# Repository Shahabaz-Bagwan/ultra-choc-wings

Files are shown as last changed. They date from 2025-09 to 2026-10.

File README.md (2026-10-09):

# Ultra Choc Wings

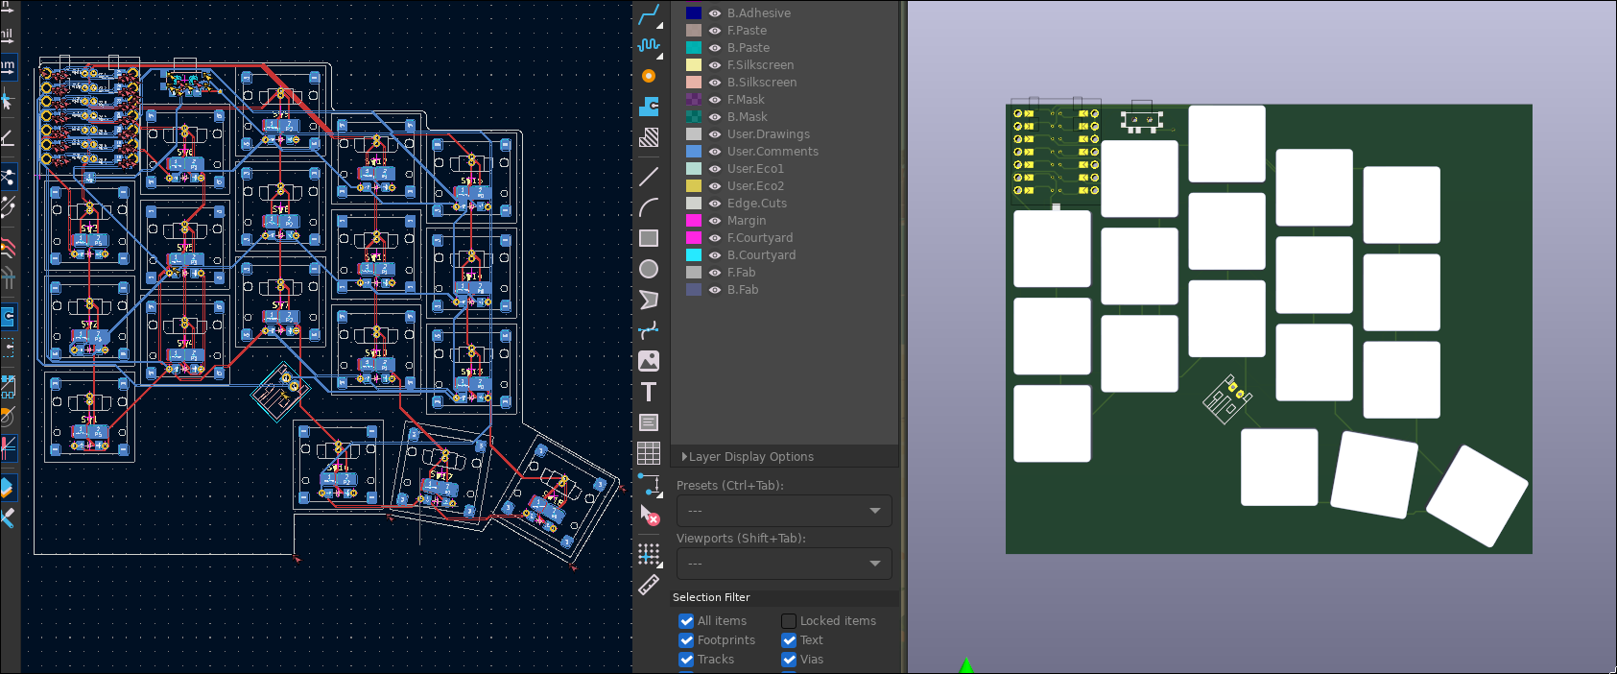
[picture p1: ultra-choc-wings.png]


A 36-key split keyboard for Kailh PG1316S switches, based on the
[Triboard](https://github.com/tarneaux/triboard).

* **36 keys**: 3×5 plus 3 thumb keys per half.
* **Chocofi layout**: 18 × 17 mm key spacing, the same column stagger and the
  same thumb cluster (0°, 15°, 30° fan) as the
  [chocofi](https://github.com/pashutk/chocofi), so keymaps, keycaps and muscle
  memory carry over. The stagger is Fifi's, which Chocofi kept in mm.
* **One reversible PCB** for both halves. The right half is the same board
  flipped over.
* **Per-key LEDs** (single colour, PWM dimmed, off by default).
* **CR2032 coin cell** per half, with a power switch.
* **ZMK with a dongle**: a third XIAO nRF52840 on USB is the central, both
  halves are low-power peripherals.
* **Seeed XIAO nRF52840** on each half.
* **JLCPCB ready**: gerbers, BOM and placement files for both halves; all SMD
  parts are assembled by JLCPCB on one side per half.
* **Two cases**: a thin folding case after Aronia's (opens flat as a uniboard,
  folds shut), and split trays that a tool-free slide-on clip joins into a rigid uniboard,
  or that work apart.

| Folder | What's in it |
| --- | --- |
| `config.yaml`, `footprints/` | Ergogen source of the PCB |
| `pcb/` | Routed KiCad board and DRC report |
| `jlcpcb/` | Gerbers, BOM and CPL files, [ordering guide](jlcpcb/README.md) |
| `firmware/` | ZMK config: dongle, left, right, keymap |
| `case/` | Folding and split cases, [notes](case/README.md) |
| `docs/power.md` | [Coin cell vs. LEDs](docs/power.md), the power budget |
| `archive/v1-lipo/` | The earlier hand-routed LiPo version |

## Coin cell and LEDs

A CR2032 cannot run 18 LEDs for long. The LEDs share one MOSFET, so when they
are off they draw nothing; the firmware keeps them off at boot, starts them at
10 % when you toggle them on (LOWER + RAISE, then `BL_TOG`), and turns them off
whenever the half goes idle. See [docs/power.md](docs/power.md) for the numbers
and the option of running from a LiPo instead.

## Firmware

`firmware/` is a ZMK user config (ZMK v0.3). GitHub Actions builds it on every
push (`.github/workflows/zmk.yml`); download the `firmware` artifact and flash:

* `ultra_choc_wings_dongle` onto the XIAO that stays plugged into the computer,
* `ultra_choc_wings_left` and `ultra_choc_wings_right` onto the halves,
* `settings_reset` first if the boards were paired to something before.

The keymap is `firmware/ultra_choc_wings.keymap` (QWERTY with LOWER, RAISE and
ADJUST layers).

## Building the PCB

```sh
npm install
KICAD_PYTHON=python3 FREEROUTING_JAR=path/to/freerouting.jar scripts/build_pcb.sh
```

This runs Ergogen, autoroutes with [Freerouting](https://github.com/freerouting/freerouting),
joins the few connections Freerouting misreads around the flippable XIAO
pads (`scripts/finish_routes.py`), adds ground pours on both layers, writes a DRC report, exports gerbers, the
JLCPCB BOM/CPL files, the schematic and the cases. It needs KiCad 7 or newer (with its Python
module), Java, and `xvfb-run` on a headless machine. The committed board was
autorouted; review it in KiCad before ordering and hand-tidy any routes you
don't like.

`pcb/drc.rpt` has no unconnected items. The remaining entries are known: the
flippable XIAO footprint's solder jumpers sit closer than the default clearance
and hole clearance by design, solder mask bridges between those jumpers,
library-footprint notes (KiCad compares the generated footprints with the
`ucw` library), and silkscreen overlaps.

## Schematic and libraries

The board comes from Ergogen, so `scripts/make_schematic.py` writes the
KiCad side from the routed board (it runs as part of `build_pcb.sh`):

* `pcb/ultra-choc-wings.kicad_sch`: every part of one half with its nets,
  as net labels, grouped into the key matrix, MCU, power and LED driver.
* `pcb/ucw.kicad_sym`: one symbol per part type.
* `pcb/ucw.pretty/`: one footprint per part type, taken from the board.
* `pcb/fp-lib-table`, `pcb/sym-lib-table`: point the project at both.

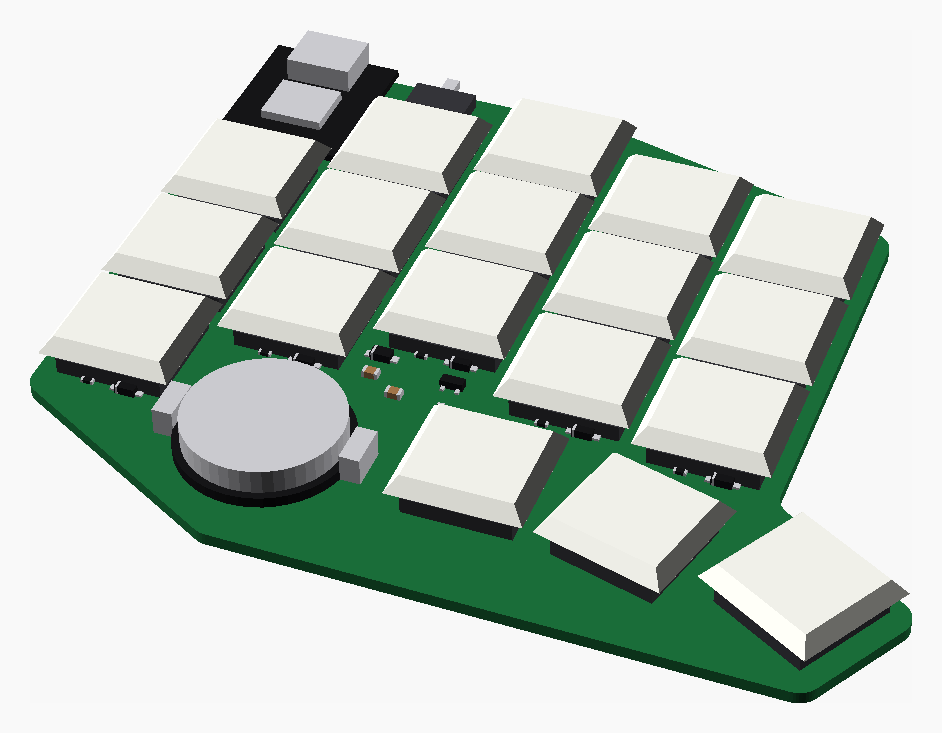
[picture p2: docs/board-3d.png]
The board with parts and keycaps


Every part also has a simple 3D model (`pcb/ucw.3dshapes/`, boxes and
cylinders from the datasheet outlines, not exact CAD), so KiCad's 3D viewer
shows the populated board; `docs/board-3d-parts.png` is the same without
keycaps. `scripts/make_3d_models.py` writes them and links them into the board
and the `ucw` footprints. The models sit on the switch side, the front (F)
for the left half.

Every footprint on the board is linked to its `ucw` footprint and to its
schematic symbol, so cross-probing and "Update PCB from Schematic" match part
for part. Change the design in `config.yaml` and rerun the build rather than
editing the schematic; the build overwrites it.

## Assembly notes

* All SMD parts, the switches and the XIAO go on the **same side** of each
  PCB: the front for the left half, the back for the right half.
* Bridge the `[> ]` jumper pads under the XIAO on the side the XIAO sits on.
* Wire the **RAW** pad (next to the XIAO) to the BAT+ pad under the XIAO.

## Credits

- Inspiration: keyboards by [GEIGEIGEIST](https://github.com/GEIGEIGEIST), the [chocofi](https://github.com/pashutk/chocofi) and the [samoklava](https://github.com/wxsh/samoklava).
- Videos by Ben Vallack on YouTube.
- Kind people on the [ErgoMechKeyboards](https://lemmy.ml/c/ergomechkeyboards@lemmy.world) Lemmy community.
- FlatFootFox - [Let's Design A Keyboard With Ergogen v4](https://flatfootfox.com/ergogen-introduction/)

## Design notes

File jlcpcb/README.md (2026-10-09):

# Ordering from JLCPCB

One PCB design is used for both halves. Order it twice: once assembled on the
top side (left half), once assembled on the bottom side (right half). The
gerbers are identical.

| File | Use |
| --- | --- |
| `gerbers.zip` | PCB, 2 layers, 1.6 mm. Same file for both orders. |
| `bom.csv` | Bill of materials (LCSC part numbers). Same file for both orders. |
| `cpl-left-top.csv` | Placement for the **left** half: assemble **Top side**. |
| `cpl-right-bottom.csv` | Placement for the **right** half: assemble **Bottom side**. |

Every SMD part is on the switch side, so each half only needs single-side
assembly. The reversible footprints mirror their copper on the back, which is
why the right half can use the exact same board flipped over;
`scripts/jlcpcb.py` checks that no copper moves when the parts are flipped.

## What JLCPCB assembles

| Ref | Part | LCSC |
| --- | --- | --- |
| D1–D18 | 1N4148WS matrix diodes (SOD-323) | C2128 |
| D19 | B5819W Schottky, reverse protection for the coin cell | C8598 |
| L1–L18 | Red LED 0603 (per key) | C2286 |
| R1–R18 | 1 kΩ 0603 (LED current) | C21190 |
| R19 | 100 kΩ 0603 (MOSFET gate pull-down) | C25803 |
| C1, C2 | 22 µF 0805 (buffer for the coin cell) | C45783 |
| Q1 | AO3400A N-MOSFET (LED switch) | C20917 |
| T1 | SPDT slide switch, power | C128955 |

Check stock and the rotation preview on JLCPCB's site before paying; the
rotations come straight from KiCad and polarised parts (diodes, LEDs, Q1) are
the ones to look at.

## What you solder yourself

* 18 Kailh PG1316S switches per half (SW1–SW18), on the same side as the parts.
* Seeed XIAO nRF52840 per half, plus one more for the dongle (no PCB needed).
  Mount it on the switch side and bridge the `[> ]` jumper pads under it on
  that side.
* CR2032 holder (BT1), MPD BC-2003 or Q&J CR2032-BS-6-1 land pattern. It is
  left out of the BOM because stock of these varies; add it to the order if
  JLCPCB has one.
* A short wire from the RAW pad to the BAT+ pad under the XIAO.

## Regenerating

`scripts/build_pcb.sh` regenerates everything in this folder from
`config.yaml`.

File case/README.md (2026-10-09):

# Cases

There are two cases. Both are built around the same board data
(`board.scad`, generated from the PCB by `scripts/make_case.py`) and give the
same uniboard outline when opened out.

| | Folding (`fold.scad`) | Split (`split.scad`) |
| --- | --- | --- |
| Style | Thin frame and bottom cover per half, after the [Aronia](https://github.com/kumekay/aronia/tree/main/case) case | Open tray per half, like the earlier one-piece tray |
| Joining | Double hinge on two brass rods: open flat as a uniboard, or fold shut like a book | One clip slides on from the back, no screws or tools: a base under both halves and a bridge across the top make a rigid uniboard; slide it off to use the halves apart |
| Size per half | about 120 × 110 × 7.2 mm; 17.8 mm thick folded | about 119 × 114 × 5.6 mm; 7.6 mm thick on the clip |

Printed STLs are in `stl/`. The right-hand parts are mirror images of the
left (the right PCB is the same board flipped over).

## Folding case

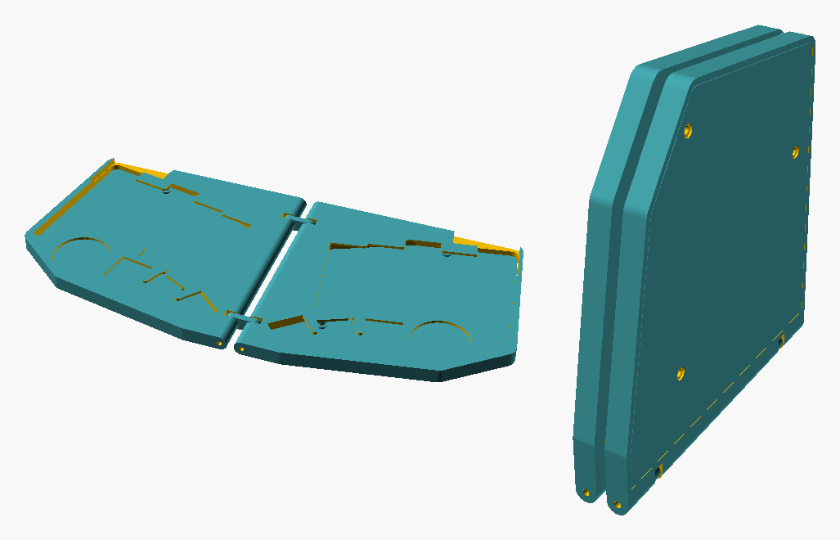
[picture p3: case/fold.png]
Folding case, open and folded


Each half is a frame around the PCB with a top deck level with the keycaps and
one opening over the key cluster, plus windows for the XIAO and the CR2032
holder. A flat cover closes the bottom.

Parts: `fold_left_frame`, `fold_right_frame`, `fold_left_cover`,
`fold_right_cover`, and 2 × `fold_link`. You also need:

* 2 × 2 mm brass rod, each about 110 mm (cut to the length of the hinge edge),
* 6 × M2 × 6 mm screws, low-profile (wafer) heads,
* stick-on rubber feet for the covers.

Assembly: put the PCB into the frame from below, switch side up. Lay the
cover on (its spacers keep the PCB 1 mm off it), and drive the three screws up
through the cover and PCB into the bosses under the deck. Stand the two halves
edge to edge, put the links into the slots, and push one rod through each
half's hinge edge and the links. Folded, the decks face each other with a gap
that clears the XIAO and the CR2032 holder.

Unlike Aronia there are no gears, so the two hinges are not synced; the halves
still fold and open, each on its own rod.

Print the frames deck down, the covers flat, the links flat. No supports.

## Split case

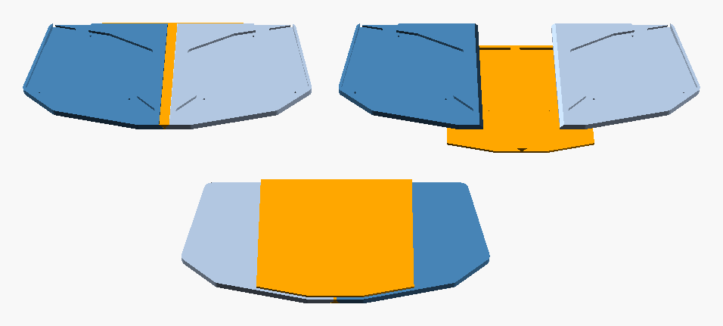
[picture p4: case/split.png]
Split case: joined, apart, and from below


Each tray is a complete case for one half: the PCB drops into its pocket and
sits flat on the floor (every SMD part is on the switch side, so the bottom is
bare), held by three M2 × 4 mm screws that self-tap into the floor. For
heat-set inserts set `pilot_d = 3.2`. The CR2032 is reachable from the top, and
a notch in the top wall clears the XIAO's USB-C port and the power switch.

To join the halves, use `split_clip`. It is shaped like an I-beam:

* a wide base plate that goes under both trays and covers about half of each
  one's underside,
* a thin web that runs up through the seam between the trays,
* a small wedge-shaped bridge on top that sits flush in a groove along the
  seam.

Lay the clip on the desk, set the two trays on it either side of the web, and
slide them forward until their back edges meet the lip at the back of the
clip, where two small bumps click into dimples under the trays. You can also
slide the clip in from the back edge of the trays. The base carries both
halves from below and the bridge holds them down from the top, so the joined
board is one rigid piece. It doesn't hinge at the seam and doesn't need a
flat surface under it. No screws or tools are needed. To split the board,
slide the clip off backwards.

If the clip is too loose or too tight on your printer, change `clip_clr`. Put
rubber feet under the clip's base and under the outer halves of the trays.

Parts: `split_left`, `split_right` and `split_clip`. Print everything flat:
the trays floor down, and the clip base down so the web and bridge print
upwards. The bridge's 45° sides need no supports.

## Changing them

Open `fold.scad` or `split.scad` in OpenSCAD and change the parameters at the
top (splay, wall and floor thickness, clearances, component heights, hinge
and clip sizes), then preview with `part = "assembly"` (or `"folded"`). Export
all STLs with `scripts/build_case.sh`.

Measure your parts before printing the folding case: `key_h` (switch height
above the PCB, sets the deck height), `xiao_h` and `coin_h` (they set the fold
gap), and `under_gap` (what pokes out under the PCB) are estimates.

`board.scad` is regenerated by `scripts/build_pcb.sh` from the routed PCB, so
both cases follow any change to `config.yaml`.

0.2 mm layers, 3 walls.

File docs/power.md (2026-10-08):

# Power: CR2032 and per-key LEDs

The halves run from a single CR2032 each. That only works because of two choices:

1. **ZMK dongle.** A third XIAO nRF52840 plugged into the computer is the split
   central. Both halves are BLE peripherals, which only talk to the dongle and
   never advertise to hosts, so the radio duty cycle on the coin cell is as
   low as ZMK gets.
2. **LEDs are off unless you ask for them.**

## Power path

```
CR2032 (+) ─ slide switch ─ B5819W Schottky ─ RAW pad ──wire──> XIAO BAT+
                                               └ 2× 22 µF to GND
```

* The Schottky stops the XIAO's Li-ion charger from ever pushing current into
  the coin cell when USB is plugged in. A CR2032 is not rechargeable.
* The 2× 22 µF buffer the radio's transmit peaks; a coin cell has 10–30 Ω of
  internal resistance and sags badly on bursts without them.
* The XIAO's own regulator then feeds the 3V3 rail (about 2.6 V on a fresh
  cell after the diode, which the nRF52840 is happy with down to 1.7 V).
* ZMK's battery percentage assumes a Li-ion cell and would always read 0 %, so
  battery reporting is turned off in the halves' config.

## The LED tradeoff

Each key has a red 0603 LED with a 1 kΩ resistor from 3V3. All 18 cathodes
share one AO3400A MOSFET switched by PWM on D6, with a 100 kΩ pull-down so the
LEDs stay dark while the MCU sleeps or boots. A MOSFET that is off draws
nothing, so the LEDs cost zero when they are off.

Rough numbers (estimated from part data, not measured):

| State | Current per half | CR2032 (≈220 mAh) lasts |
| --- | --- | --- |
| Asleep (ZMK deep sleep) | ~5 µA | years |
| Connected, typing, LEDs off | ~30–60 µA average | several months |
| LEDs on at 10 % (default when toggled) | +~1.5 mA | about 4–6 days of LEDs-on time |
| LEDs on at 100 % | +~15 mA | under a day, with heavy voltage sag |

So the firmware defaults are:

* LEDs **off at boot** (`CONFIG_ZMK_BACKLIGHT_ON_START=n`)
* **10 %** brightness when switched on (`CONFIG_ZMK_BACKLIGHT_BRT_START=10`)
* **off whenever the half goes idle** (`CONFIG_ZMK_BACKLIGHT_AUTO_OFF_IDLE=y`)
* toggle and dim on the ADJUST layer (hold LOWER + RAISE): `BL_TOG`, `BL_DEC`, `BL_INC`

If you want the LEDs on a lot, skip the coin cell: solder a small 3.7 V LiPo
straight to the RAW pad and GND (leave the coin cell holder empty). The XIAO
then charges it over USB.

## LED colour and voltage

Red was picked because its forward voltage (~1.8 V) still leaves headroom on a
2.4–2.6 V rail as the cell drains. Blue or white LEDs (~2.8–3 V) would not light
from a coin cell.

## Not yet verified on hardware

* Light through the PG1316S housing. The LED sits in the component pocket under
  the switch (the area marked on Dwgs.User in the PG1316S footprint). Whether
  enough light makes it through the switch to the keycap needs one test switch
  before ordering a full set of LEDs. If it does not, leave L1–L18 off the
  JLCPCB order; nothing else depends on them.

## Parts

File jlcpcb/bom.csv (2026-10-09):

Comment | Designator | Footprint | LCSC Part #
Resistor 100k 1% 0603 | R19 | 0603 | C25803
Switching diode 1N4148WS | D1,D2,D3,D4,D5,D6,D7,D8,D9,D10,D11,D12,D13,D14,D15,D16,D17,D18 | SOD-323 | C2128
Resistor 1k 1% 0603 | R1,R2,R3,R4,R5,R6,R7,R8,R9,R10,R11,R12,R13,R14,R15,R16,R17,R18 | 0603 | C21190
Capacitor 22uF 25V X5R 0805 | C1,C2 | 0805 | C45783
N-MOSFET AO3400A | Q1 | SOT-23 | C20917
Schottky diode 40V 1A B5819W | D19 | SOD-123 | C8598
LED red 0603 | L1,L2,L3,L4,L5,L6,L7,L8,L9,L10,L11,L12,L13,L14,L15,L16,L17,L18 | 0603 | C2286
Slide switch SPDT (C128955 land pattern) | T1 | SMD | C128955

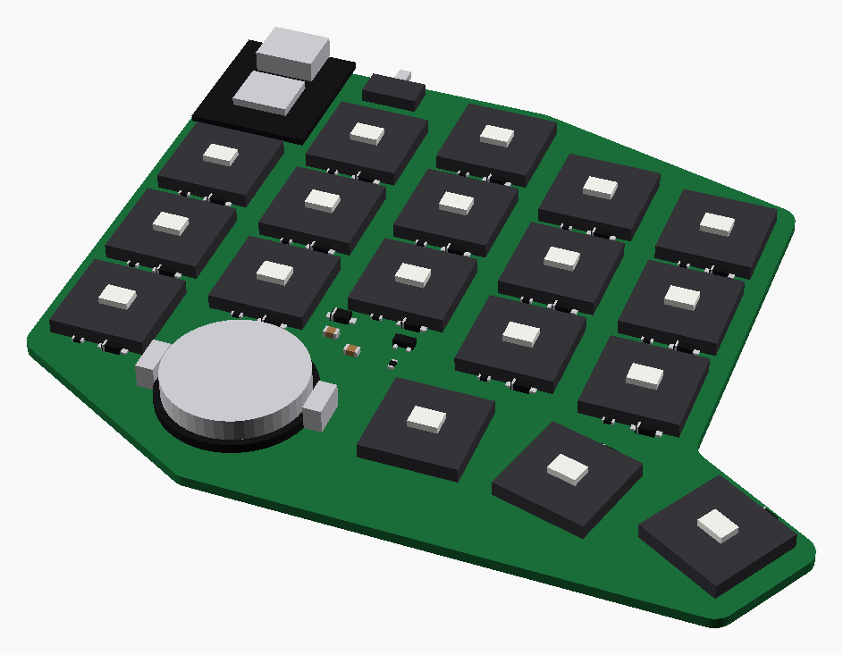
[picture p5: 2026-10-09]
docs/board-3d-parts.png

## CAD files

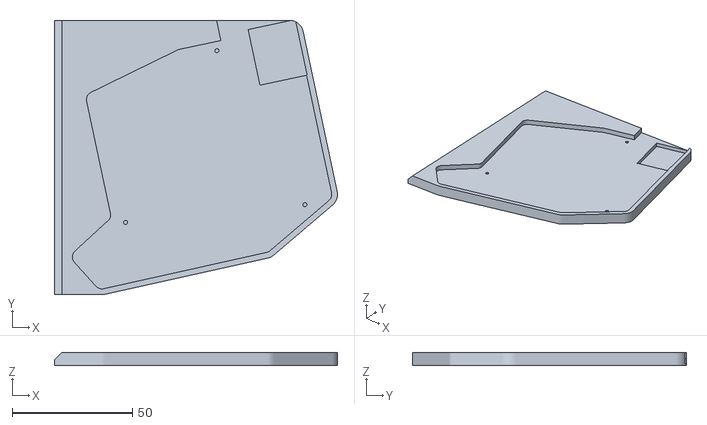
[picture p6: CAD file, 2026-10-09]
case/stl/split_right.stl
117.8 x 114.1 x 5.60

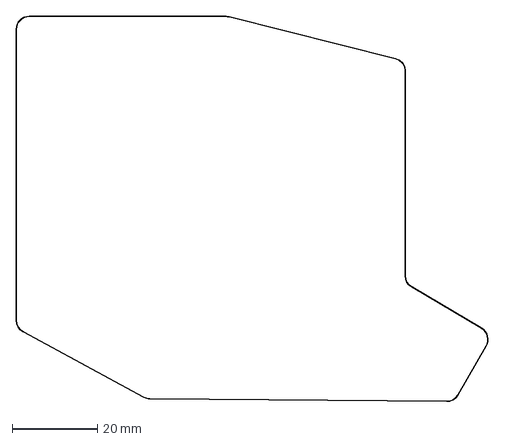
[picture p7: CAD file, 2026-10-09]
output/outlines/board.dxf
110.7 x 90.1 mm

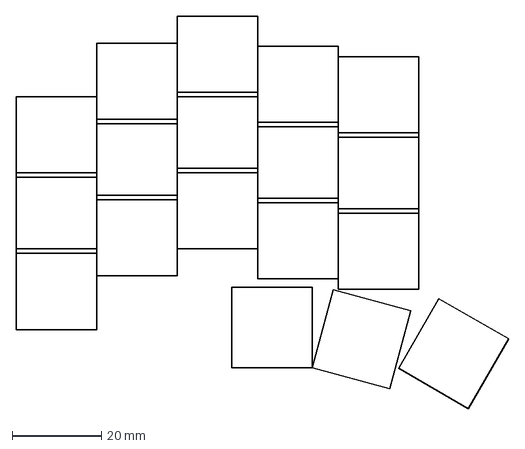
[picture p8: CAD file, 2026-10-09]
output/points/demo.dxf
110.0 x 87.7 mm

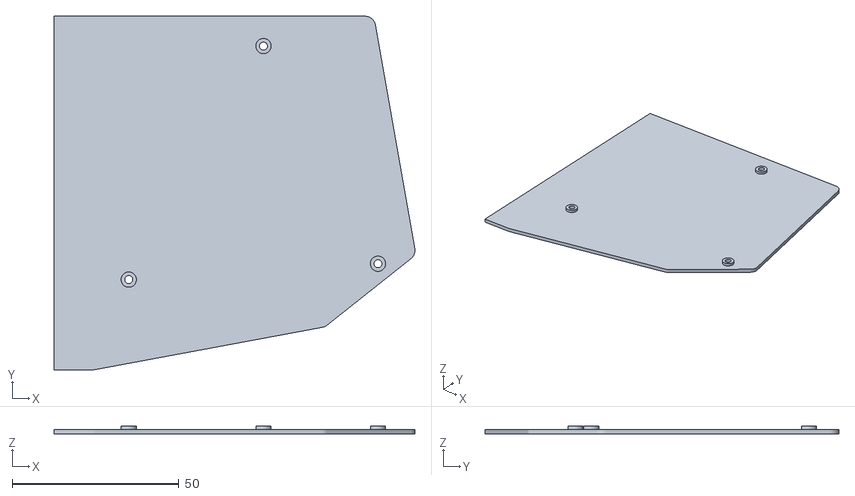
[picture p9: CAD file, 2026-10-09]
case/stl/fold_right_cover.stl
108.4 x 106.1 x 2.40

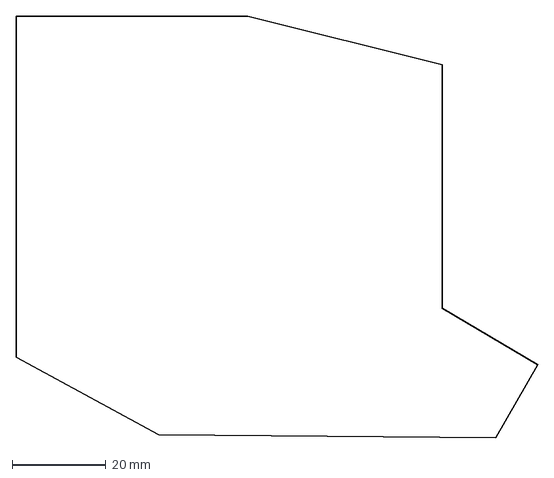
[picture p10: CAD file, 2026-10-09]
output/outlines/board_noround.dxf
111.4 x 90.1 mm

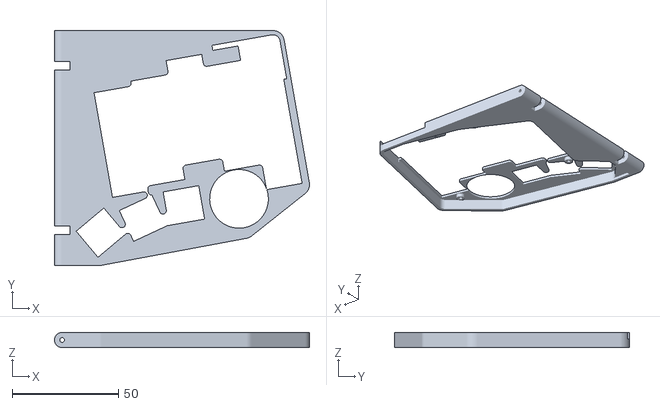
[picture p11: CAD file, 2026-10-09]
case/stl/fold_right_frame.stl
120.0 x 110.5 x 7.20

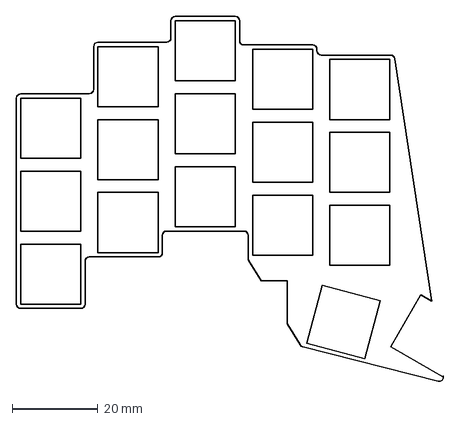
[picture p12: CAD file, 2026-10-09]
output/outlines/top_plate.dxf
99.5 x 85.0 mm

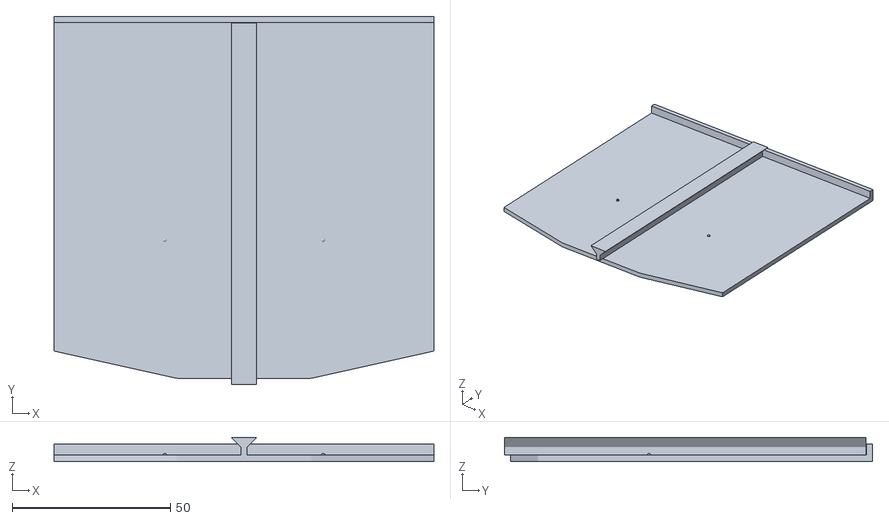
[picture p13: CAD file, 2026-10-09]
case/stl/split_clip.stl
120.0 x 116.3 x 7.60

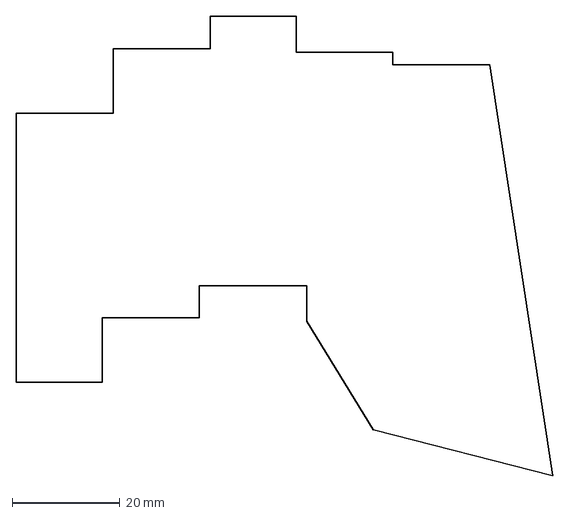
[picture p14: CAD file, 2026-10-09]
output/outlines/top_plate_base.dxf
99.7 x 85.3 mm

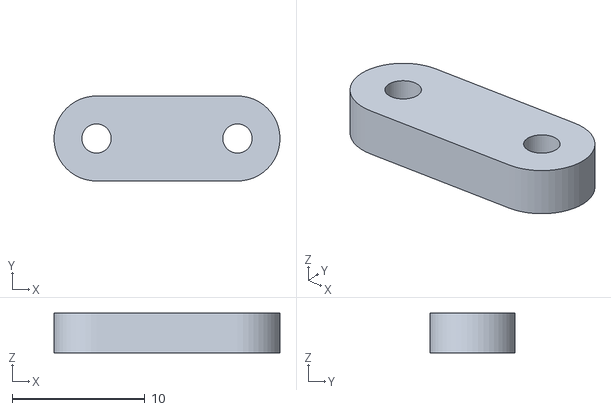
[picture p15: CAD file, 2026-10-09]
case/stl/fold_link.stl
17.0 x 6.40 x 3.00

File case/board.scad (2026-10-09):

// Ultra Choc Wings board geometry, generated by scripts/make_case.py from
// pcb/ultra-choc-wings.kicad_pcb. Do not edit: rerun scripts/build_pcb.sh.
// Coordinates are the left half, switch side up, in mm, y up.

board = [[39.997, 62.877], [40.359, 62.81], [79.229, 53.069], [79.574, 52.96], [79.903, 52.811], [80.211, 52.623], [80.495, 52.4], [80.75, 52.144], [80.972, 51.859], [81.158, 51.549], [81.306, 51.22], [81.413, 50.875], [81.478, 50.52], [81.5, 50.159], [81.5, 2.209], [81.52, 1.865], [81.579, 1.525], [81.677, 1.194], [81.812, 0.877], [81.983, 0.577], [82.187, 0.298], [82.422, 0.046], [82.684, -0.179], [82.971, -0.371], [99.359, -10.084], [99.636, -10.27], [99.891, -10.485], [100.121, -10.728], [100.322, -10.995], [100.492, -11.282], [100.629, -11.587], [100.731, -11.904], [100.798, -12.232], [100.828, -12.564], [100.82, -12.898], [100.776, -13.229], [100.694, -13.553], [100.578, -13.866], [100.427, -14.164], [93.786, -25.668], [93.592, -25.962], [93.365, -26.231], [93.109, -26.472], [92.826, -26.681], [92.52, -26.856], [92.196, -26.993], [91.858, -27.092], [91.511, -27.15], [91.159, -27.168], [21.744, -26.507], [21.381, -26.481], [21.023, -26.412], [20.676, -26.3], [20.345, -26.146], [-7.927, -10.851], [-8.232, -10.662], [-8.511, -10.438], [-8.762, -10.183], [-8.981, -9.899], [-9.164, -9.591], [-9.309, -9.264], [-9.415, -8.922], [-9.479, -8.57], [-9.5, -8.212], [-9.5, 59.9], [-9.481, 60.236], [-9.425, 60.568], [-9.332, 60.891], [-9.203, 61.202], [-9.04, 61.496], [-8.845, 61.77], [-8.621, 62.021], [-8.37, 62.245], [-8.096, 62.44], [-7.802, 62.603], [-7.491, 62.732], [-7.168, 62.825], [-6.836, 62.881], [-6.5, 62.9], [39.63, 62.9]];
board_top = 62.9;
holes = [[24.5, 59.5], [2.0, -10.8], [76.5, -2.5]];        // M2 mounting holes
keys = [[0.0, -0.0, 0.0], [54.0, 11.375, 0.0], [54.0, 28.375, 0.0], [54.0, 45.375, 0.0], [72.0, 9.0, 0.0], [72.0, 26.0, 0.0], [72.0, 43.0, 0.0], [48.1, -8.59, 0.0], [68.15, -11.18, -15.0], [88.75, -14.39, -30.0], [0.0, 17.0, 0.0], [0.0, 34.0, 0.0], [18.0, 12.0, 0.0], [18.0, 29.0, 0.0], [18.0, 46.0, 0.0], [36.0, 18.0, 0.0], [36.0, 35.0, 0.0], [36.0, 52.0, 0.0]];          // switch centres [x, y, rotation]
xiao_box = [-9.14, 42.75, 8.95, 64.41];           // XIAO footprint [x0, y0, x1, y1]
power_switch = [17.0, 59.9];   // slide switch centre, on the top edge
coin = [22.0, -10.0];         // CR2032 holder centre

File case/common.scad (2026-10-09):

// Shared helpers for fold.scad and split.scad.
include <board.scad>

function rot(p, a) = [p[0] * cos(a) - p[1] * sin(a), p[0] * sin(a) + p[1] * cos(a)];

// x of the innermost (thumb side) board point once the half is splayed.
function inner_x(splay) = max([for (p = board) rot(p, -splay)[0]]);
function board_ys(splay) = [for (p = board) rot(p, -splay)[1]];

// Put the left half at its splay with its innermost point at x = -inner.
// The right half is the mirror image (the same PCB, flipped over).
module place_left(splay, inner) translate([-inner - inner_x(splay), 0]) rotate(-splay) children();
module place_right(splay, inner) mirror([1, 0, 0]) place_left(splay, inner) children();

module board_shape() polygon(board);

// One opening per keycap, merged where the ribs between them would be
// thinner than 2 * merge.
module key_openings(w, h, merge)
    offset(r = -merge) offset(delta = merge)
        for (k = keys) translate([k[0], k[1]]) rotate(k[2]) square([w, h], center = true);

module xiao_shape(grow = 1)
    offset(delta = grow) translate([xiao_box[0], xiao_box[1]])
        square([xiao_box[2] - xiao_box[0], xiao_box[3] - xiao_box[1]]);

// XIAO USB-C and the slide switch both stick out of the top edge; one notch
// in the wall clears both.
module top_notch(depth)
    translate([xiao_box[0] - 1, board_top - 2])
        square([power_switch[0] + 5 - (xiao_box[0] - 1), depth + 2]);

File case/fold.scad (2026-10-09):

// Ultra Choc Wings folding case, after the Aronia case
// (https://github.com/kumekay/aronia/tree/main/case).
//
// Each half is a thin frame that wraps the PCB, with a top deck level with
// the keycaps and one opening over the keys, and a flat bottom cover. Three
// M2 x 6 mm screws per half go up through the cover, a printed spacer and the
// PCB into bosses under the deck, so they clamp the whole stack. The two
// halves are joined along their straight inner edges by a double hinge: each
// half turns on its own 2 mm brass rod, and printed links tie the two rods
// together. Open, it is a uniboard at a fixed splay; folded, the halves close
// keys to keys like a book, with a gap sized for the XIAO and the CR2032
// holder that stand above the deck.
//
// Export one part at a time, e.g.
//   openscad -D 'part="left_frame"' -o fold_left_frame.stl fold.scad

include <common.scad>

/* [Part] */
part = "assembly"; // [assembly, folded, left_frame, right_frame, left_cover, right_cover, link]

/* [Layout] */
splay = 10;        // degrees each half is rotated away from the hinge line
/* [Stack-up] */
cover_t = 1.4;     // bottom cover
under_gap = 1.0;   // space under the PCB for switch pegs and solder
pcb_t = 1.6;
key_h = 3.2;       // deck top above the PCB top; about the PG1316S height, so caps sit flush
deck_t = 1.2;      // deck thickness
wall = 2.0;        // side wall thickness
clearance = 0.4;   // gap between PCB edge and frame
/* [Keys] */
key_w = 17;        // opening per keycap, across
key_d = 16;        // opening per keycap, front to back
key_merge = 1.6;   // merge openings closer than 2 * key_merge into one
/* [Parts above the deck] */
xiao_h = 3.6;      // XIAO height above the PCB
coin_h = 4.6;      // CR2032 holder height above the PCB
coin_window = 13.8; // radius of the opening over the CR2032 holder
notch_depth = 10;  // how far the USB-C / switch notch reaches into the wall
/* [Hinge] */
axle_d = 2.0;      // brass rod
axle_clr = 0.2;
links = 2;
link_t = 3;        // link thickness
slot_clr = 0.4;    // clearance around the links
/* [Screws] */
pilot_d = 1.7;     // M2 self-tapping pilot in the deck bosses
boss_d = 4.6;
screw_d = 2.4;     // clearance hole in the cover
head_d = 4.2;      // counterbore for the screw head
head_depth = 0.6;
$fn = 48;

H = cover_t + under_gap + pcb_t + key_h;  // overall thickness of one half
z_pcb = cover_t + under_gap;
z_top = z_pcb + pcb_t;
// Folded, the two decks face each other; leave room for what stands above them.
fold_gap = max(0, 2 * (max(xiao_h, coin_h) - key_h)) + 0.6;
s = (H + fold_gap) / 2;          // the left axle runs along x = -s, z = H / 2
r_link = H / 2 - 0.4;
hinge_band = r_link + slot_clr;  // depth of the link slots behind the axle
inner = s + hinge_band + wall + clearance;  // seam to the PCB
y_lo = min(board_ys(splay)) - wall - clearance;
y_hi = max(board_ys(splay)) + wall + clearance;
link_ys = [for (i = [0 : links - 1])
    y_lo + (y_hi - y_lo) * (links == 1 ? 0.5 : 0.15 + 0.7 * i / (links - 1))];

module left() place_left(splay, inner) children();

// Outline of the opened keyboard, cut at the left half's hinge edge.
module half_outline()
    intersection() {
        offset(r = wall + clearance) hull() { left() board_shape(); place_right(splay, inner) board_shape(); }
        translate([-1000, -1000]) square([1000 - s + H / 2, 2000]);
    }

// Inside of the frame below the PCB, kept clear of the hinge.
module cover_shape()
    offset(r = -wall) intersection() {
        half_outline();
        translate([-1000, -1000]) square([1000 - s - hinge_band, 2000]);
    }

module along_y(len = 1000) rotate([90, 0, 0]) cylinder(h = len, center = true, r = 1);

module left_frame() {
    difference() {
        union() {
            difference() {
                linear_extrude(H) half_outline();
                // Round the hinge edge into a half cylinder around the axle.
                translate([-s, 0, H / 2]) difference() {
                    translate([0, -1000, -H]) cube([H, 2000, 2 * H]);
                    scale([H / 2, 1, H / 2]) along_y();
                }
                // Room for the cover, the space under the PCB, and the PCB.
                translate([0, 0, -1]) linear_extrude(cover_t + 1) cover_shape();
                translate([0, 0, cover_t - 0.01]) linear_extrude(H - deck_t - cover_t + 0.01)
                    left() offset(delta = clearance) board_shape();
            }
            // Screw bosses from the PCB up to the deck.
            left() for (p = holes) translate([p[0], p[1], z_top]) cylinder(d = boss_d, h = H - z_top - deck_t + 0.01);
        }
        // Deck openings: keys, XIAO, CR2032, and the top-edge notch.
        translate([0, 0, z_top + 0.2]) linear_extrude(H) left() {
            key_openings(key_w, key_d, key_merge);
            xiao_shape();
            translate(coin) circle(r = coin_window);
        }
        translate([0, 0, z_top]) linear_extrude(H) left() top_notch(notch_depth);
        // Axle and link slots.
        translate([-s, 0, H / 2]) scale([(axle_d + axle_clr) / 2, 1, (axle_d + axle_clr) / 2]) along_y();
        for (y = link_ys) translate([-s - hinge_band, y - link_t / 2 - slot_clr, -1])
            cube([H + 1, link_t + 2 * slot_clr, H + 2]);
        // M2 pilots, stopping 0.6 mm under the deck top.
        left() for (p = holes) translate([p[0], p[1], z_top - 0.01]) cylinder(d = pilot_d, h = H - z_top - 0.6);
    }
}

module left_cover() {
    difference() {
        union() {
            linear_extrude(cover_t) offset(delta = -0.2) cover_shape();
            // Spacers that hold the PCB off the cover, trimmed to the PCB pocket.
            intersection() {
                left() for (p = holes) translate([p[0], p[1], cover_t - 0.01]) cylinder(d = boss_d, h = under_gap + 0.01);
                linear_extrude(H) left() board_shape();
            }
        }
        left() for (p = holes) translate([p[0], p[1], 0]) {
            translate([0, 0, -1]) cylinder(d = screw_d, h = H);
            translate([0, 0, -1]) cylinder(d = head_d, h = head_depth + 1);
        }
    }
}

module link()
    difference() {
        hull() for (x = [0, 2 * s]) translate([x, 0]) circle(r = r_link);
        for (x = [0, 2 * s]) translate([x, 0]) circle(d = axle_d + axle_clr);
    }

module left_half() { color("DimGray") left_frame(); color("Gray") left_cover(); }
module links_in_place()
    color("Orange") for (y = link_ys) translate([-s, y + link_t / 2, H / 2]) rotate([90, 0, 0]) linear_extrude(link_t) link();

if (part == "left_frame") left_frame();
else if (part == "right_frame") mirror([1, 0, 0]) left_frame();
else if (part == "left_cover") left_cover();
else if (part == "right_cover") mirror([1, 0, 0]) left_cover();
else if (part == "link") linear_extrude(link_t) link();
else if (part == "folded") {
    // Links stay put; each half turns 90 degrees about its own axle.
    links_in_place();
    translate([-s, 0, H / 2]) rotate([0, 90, 0]) translate([s, 0, -H / 2]) left_half();
    mirror([1, 0, 0]) translate([-s, 0, H / 2]) rotate([0, 90, 0]) translate([s, 0, -H / 2]) left_half();
} else {
    left_half();
    mirror([1, 0, 0]) left_half();
    links_in_place();
}

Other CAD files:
case/stl/split_left.stl
case/stl/fold_left_frame.stl
case/stl/fold_left_cover.stl
case/split.scad
case/ultra_choc_wings_case.scad

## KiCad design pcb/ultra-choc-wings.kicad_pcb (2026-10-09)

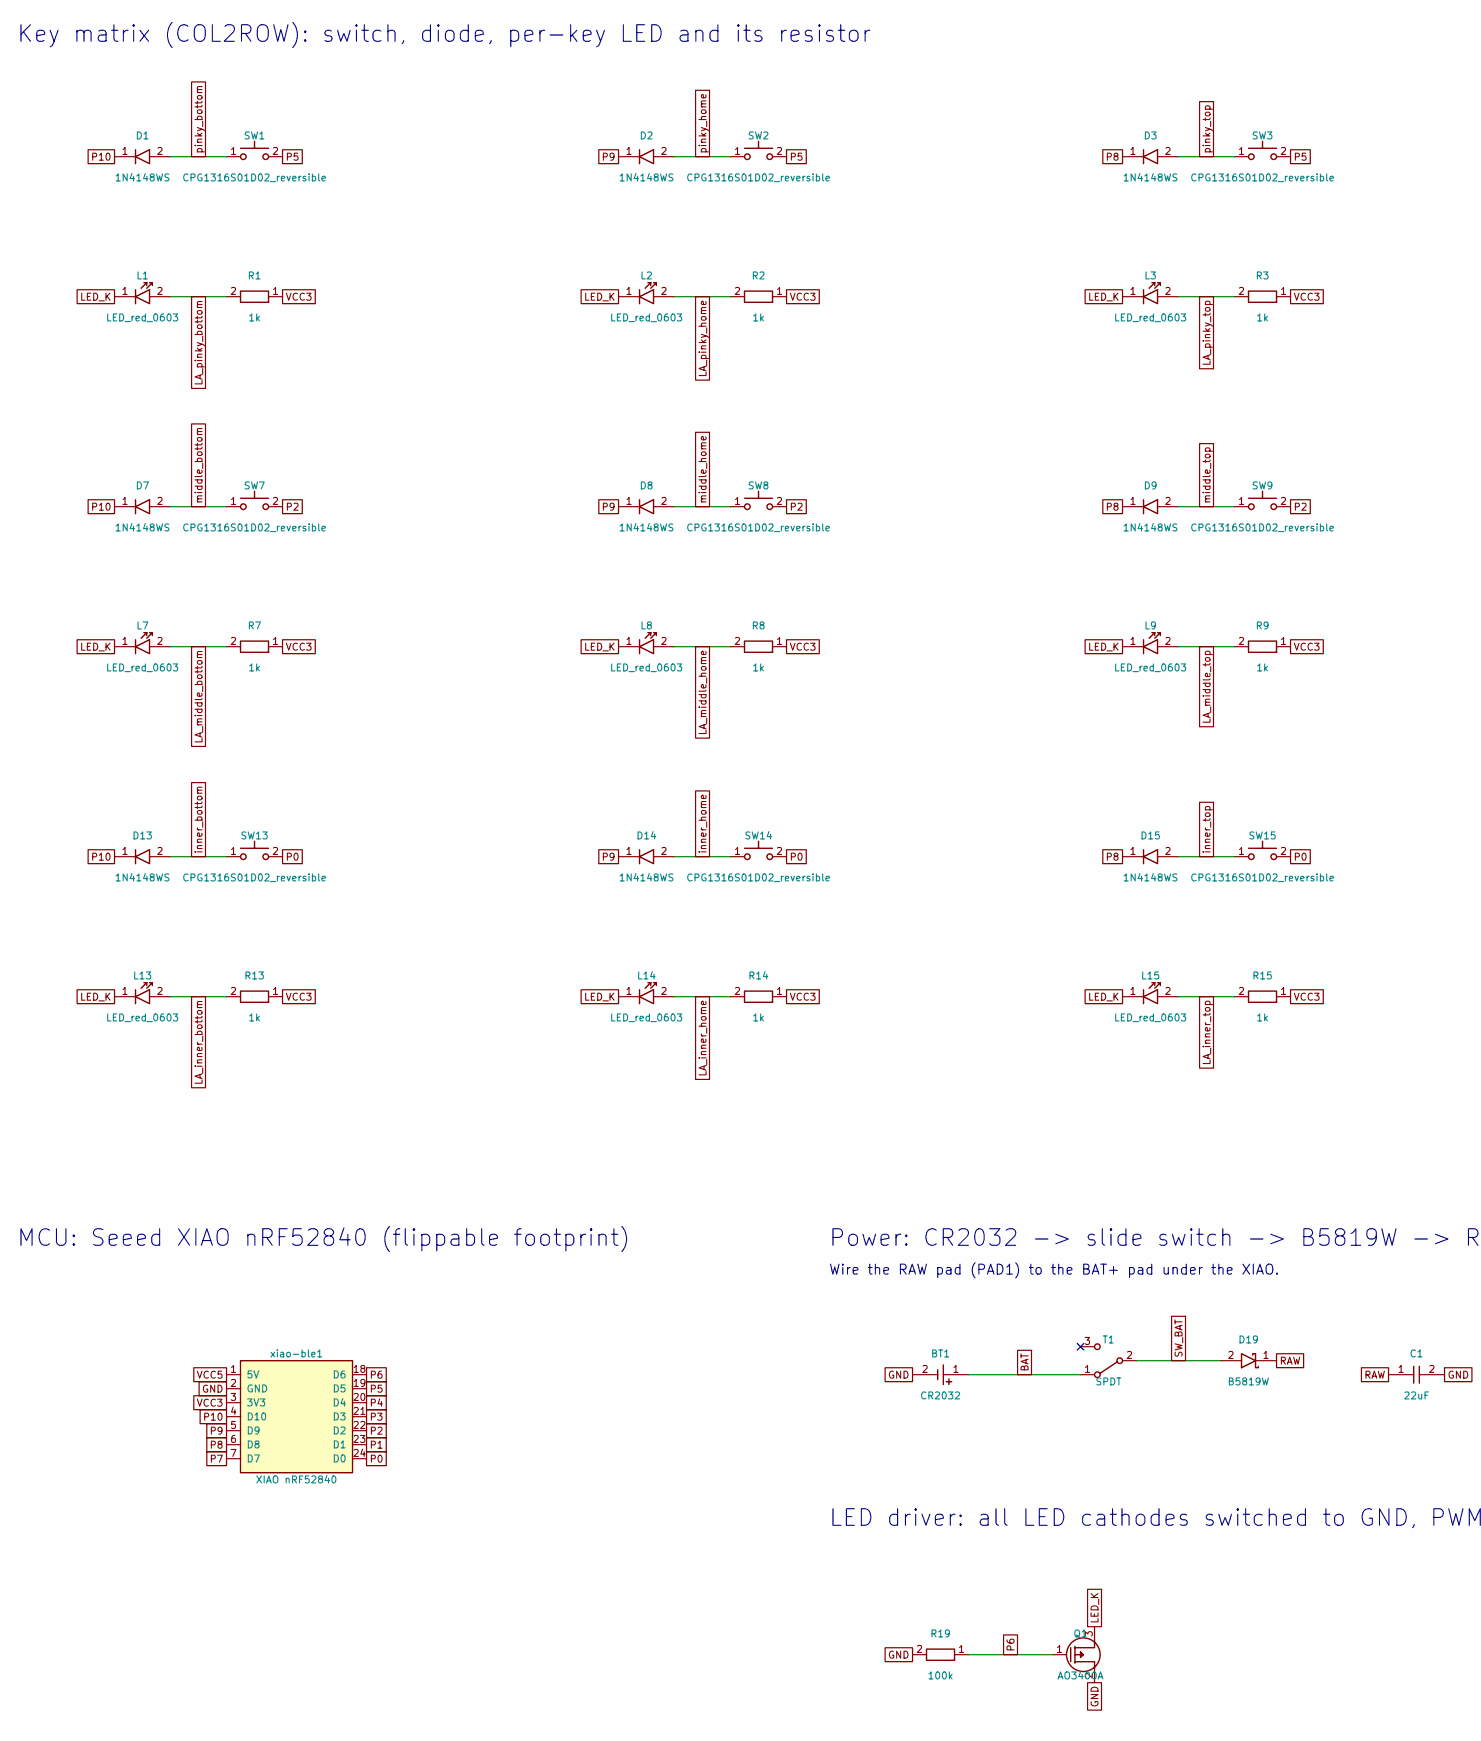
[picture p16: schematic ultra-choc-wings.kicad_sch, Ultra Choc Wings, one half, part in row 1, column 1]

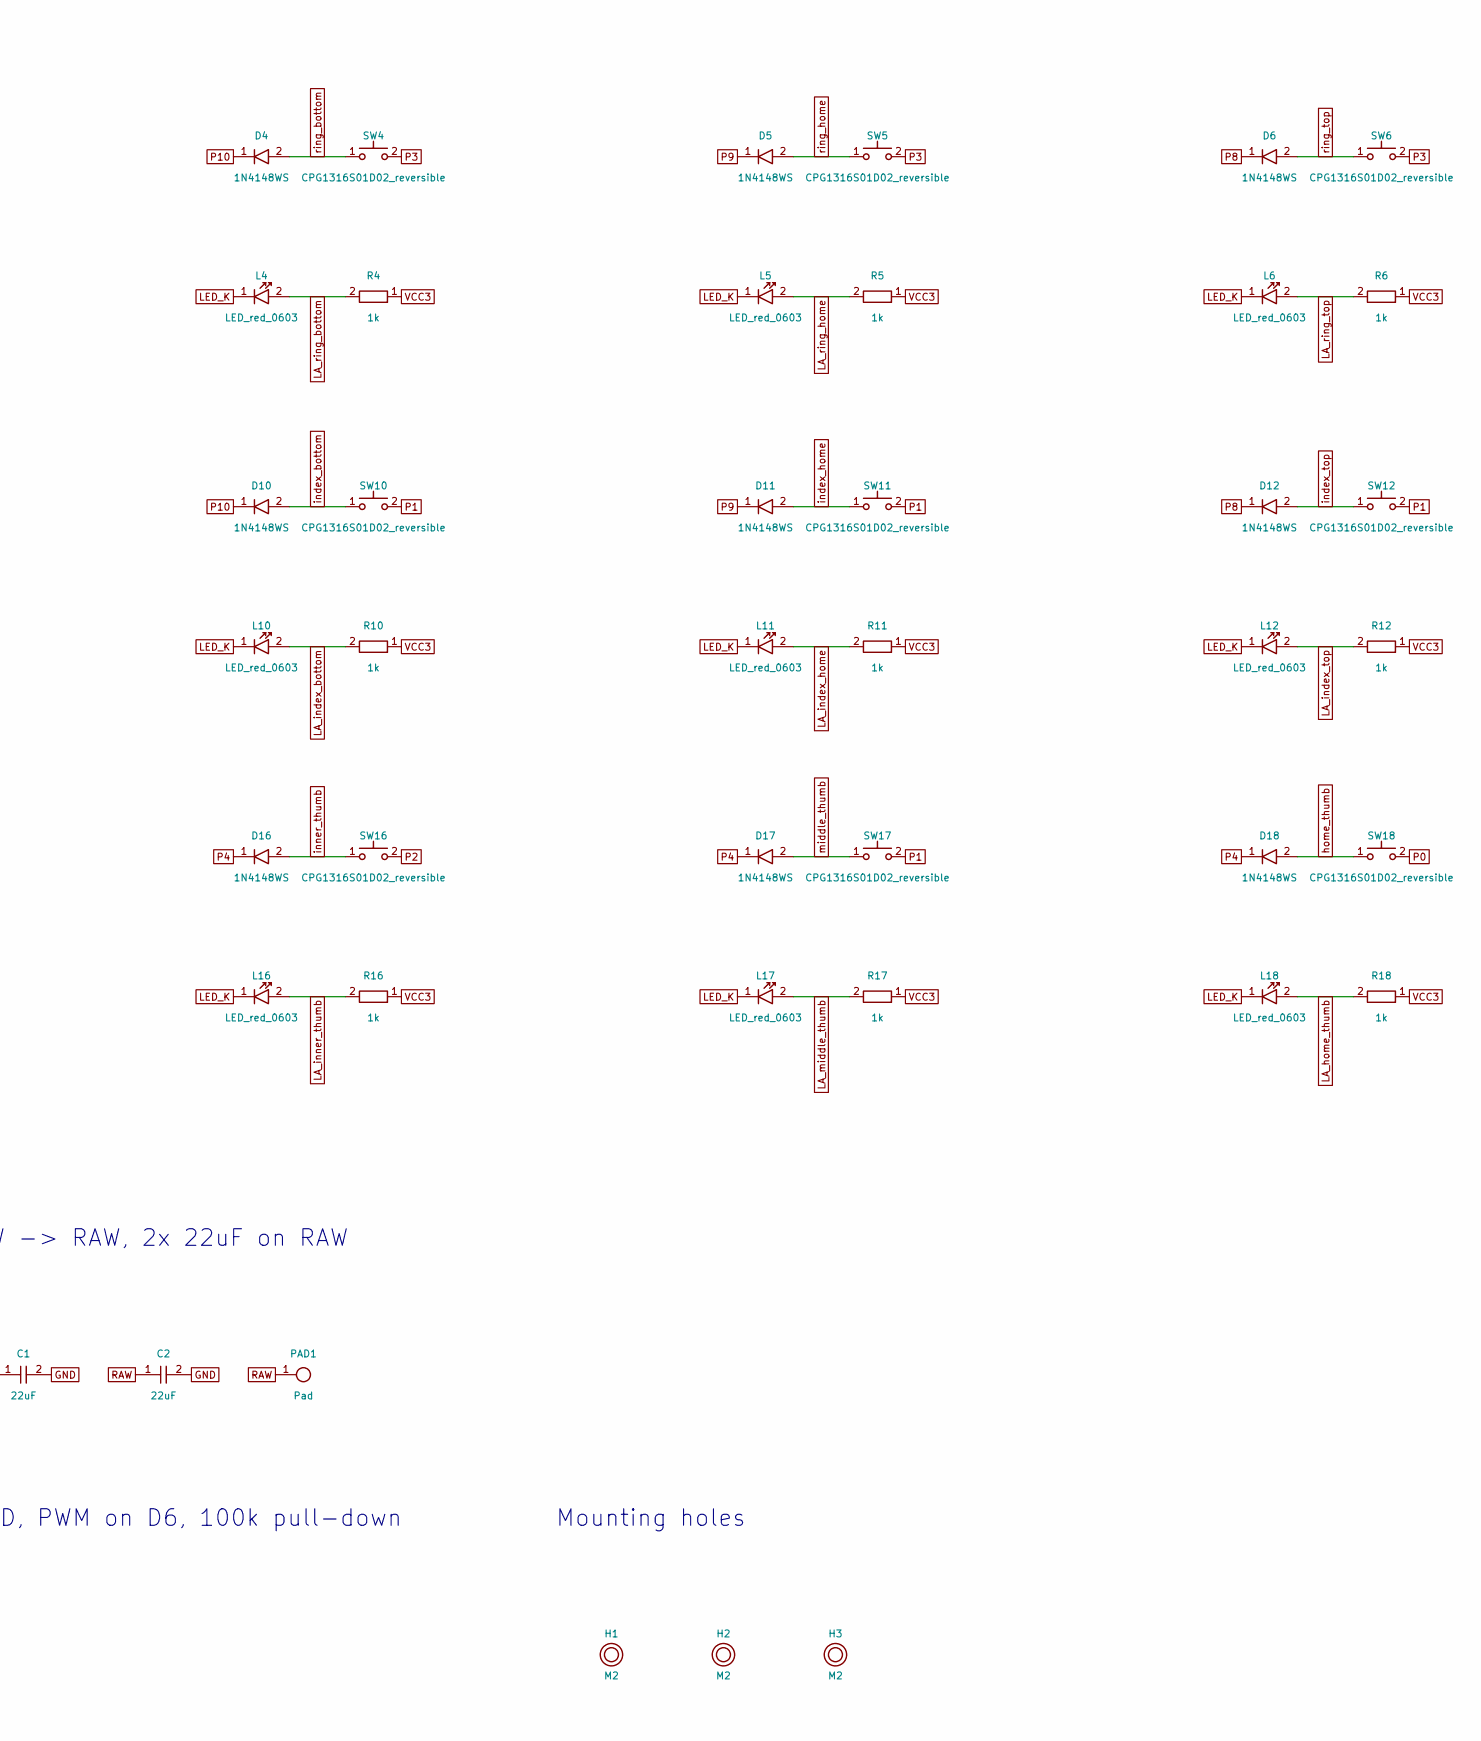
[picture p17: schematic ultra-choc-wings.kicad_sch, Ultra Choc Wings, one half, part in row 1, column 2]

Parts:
BT1: CR2032; REV_CR2032_BC2003
C1, C2: 22uF; REV_0805; LCSC C45783
D1, D2, D3, D4, D5, D6, D7, D8, D9, D10, D11, D12, D13, D14, D15, D16, D17, D18: 1N4148WS; REV_SOD323; LCSC C2128
D19: B5819W; REV_SOD123; LCSC C8598
H1, H2, H3: M2; M2_NPTH
L1, L2, L3, L4, L5, L6, L7, L8, L9, L10, L11, L12, L13, L14, L15, L16, L17, L18: LED_red_0603; REV_LED0603; LCSC C2286
PAD1: Pad; SMDPad
Q1: AO3400A; REV_SOT-23; LCSC C20917
R1, R2, R3, R4, R5, R6, R7, R8, R9, R10, R11, R12, R13, R14, R15, R16, R17, R18: 1k; REV_0603; LCSC C21190
R19: 100k; REV_0603; LCSC C25803
SW1, SW2, SW3, SW4, SW5, SW6, SW7, SW8, SW9, SW10, SW11, SW12, SW13, SW14, SW15, SW16, SW17, SW18: CPG1316S01D02_reversible
T1: SPDT; REV_SPDT_C128955; LCSC C128955
xiao-ble1: XIAO nRF52840; xiao-ble

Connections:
BAT: BT1.1, T1.1
GND: BT1.2, C1.2, C2.2, Q1.2 (S), R19.2, xiao-ble1.2 (GND)
LA_home_thumb: L18.2, R18.2
LA_index_bottom: L10.2, R10.2
LA_index_home: L11.2, R11.2
LA_index_top: L12.2, R12.2
LA_inner_bottom: L13.2, R13.2
LA_inner_home: L14.2, R14.2
LA_inner_thumb: L16.2, R16.2
LA_inner_top: L15.2, R15.2
LA_middle_bottom: L7.2, R7.2
LA_middle_home: L8.2, R8.2
LA_middle_thumb: L17.2, R17.2
LA_middle_top: L9.2, R9.2
LA_pinky_bottom: L1.2, R1.2
LA_pinky_home: L2.2, R2.2
LA_pinky_top: L3.2, R3.2
LA_ring_bottom: L4.2, R4.2
LA_ring_home: L5.2, R5.2
LA_ring_top: L6.2, R6.2
LED_K: L1.1, L2.1, L3.1, L4.1, L5.1, L6.1, L7.1, L8.1, L9.1, L10.1, L11.1, L12.1, L13.1, L14.1, L15.1, L16.1, L17.1, L18.1, Q1.3 (D)
P0: SW13.2, SW14.2, SW15.2, SW18.2, xiao-ble1.24 (D0)
P1: SW10.2, SW11.2, SW12.2, SW17.2, xiao-ble1.23 (D1)
P2: SW7.2, SW8.2, SW9.2, SW16.2, xiao-ble1.22 (D2)
P3: SW4.2, SW5.2, SW6.2, xiao-ble1.21 (D3)
P4: D16.1, D17.1, D18.1, xiao-ble1.20 (D4)
P5: SW1.2, SW2.2, SW3.2, xiao-ble1.19 (D5)
P6: Q1.1 (G), R19.1, xiao-ble1.18 (D6)
P7: xiao-ble1.7 (D7)
P8: D3.1, D6.1, D9.1, D12.1, D15.1, xiao-ble1.6 (D8)
P9: D2.1, D5.1, D8.1, D11.1, D14.1, xiao-ble1.5 (D9)
P10: D1.1, D4.1, D7.1, D10.1, D13.1, xiao-ble1.4 (D10)
RAW: C1.1, C2.1, D19.1, PAD1.1
SW_BAT: D19.2, T1.2
VCC3: R1.1, R2.1, R3.1, R4.1, R5.1, R6.1, R7.1, R8.1, R9.1, R10.1, R11.1, R12.1, R13.1, R14.1, R15.1, R16.1, R17.1, R18.1, xiao-ble1.3 (3V3)
VCC5: xiao-ble1.1 (5V)
home_thumb: D18.2, SW18.1
index_bottom: D10.2, SW10.1
index_home: D11.2, SW11.1
index_top: D12.2, SW12.1
inner_bottom: D13.2, SW13.1
inner_home: D14.2, SW14.1
inner_thumb: D16.2, SW16.1
inner_top: D15.2, SW15.1
middle_bottom: D7.2, SW7.1
middle_home: D8.2, SW8.1
middle_thumb: D17.2, SW17.1
middle_top: D9.2, SW9.1
pinky_bottom: D1.2, SW1.1
pinky_home: D2.2, SW2.1
pinky_top: D3.2, SW3.1
ring_bottom: D4.2, SW4.1
ring_home: D5.2, SW5.1
ring_top: D6.2, SW6.1

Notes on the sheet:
Key matrix (COL2ROW): switch, diode, per-key LED and its resistor
MCU: Seeed XIAO nRF52840 (flippable footprint)
Power: CR2032 -> slide switch -> B5819W -> RAW, 2x 22uF on RAW
Wire the RAW pad (PAD1) to the BAT+ pad under the XIAO.
LED driver: all LED cathodes switched to GND, PWM on D6, 100k pull-down
Mounting holes

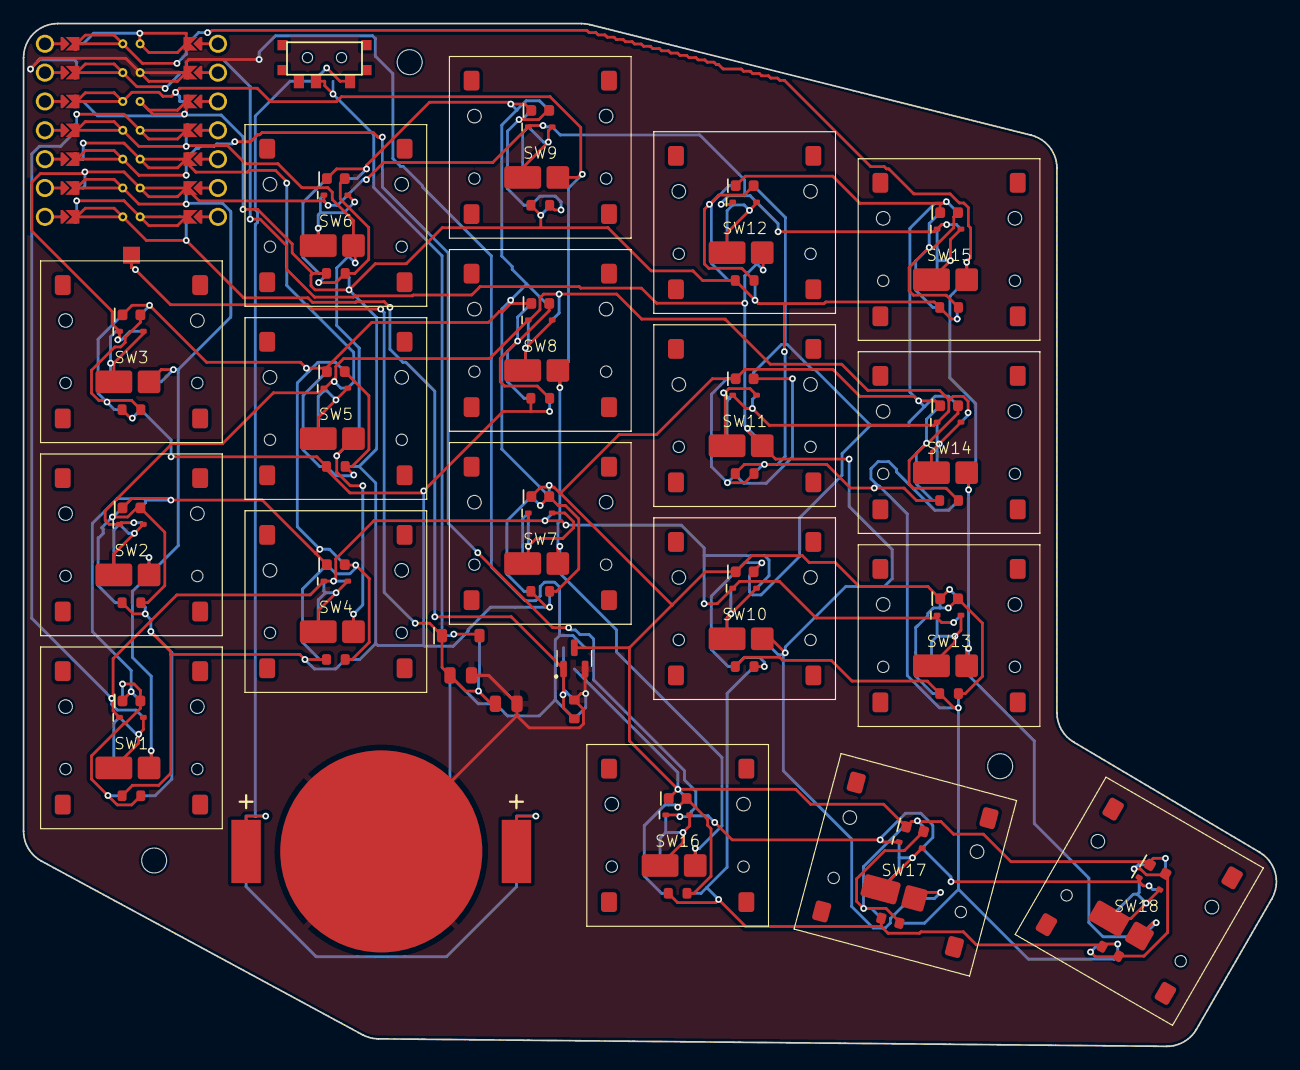
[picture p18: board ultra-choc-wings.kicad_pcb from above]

Board: 2 copper layers, 110.3 x 90.1 mm, 84 parts (0 on the bottom side), 52 nets.

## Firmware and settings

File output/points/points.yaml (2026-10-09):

matrix_pinky_bottom:
    x: 0
    'y': 0
    r: 0
    meta:
        stagger: 0
        spread: 18
        splay: 0
        origin:
            - 0
            - 0
        orient: 0
        shift:
            - 0
            - 0
        rotate: 0
        adjust: {}
        width: 18
        height: 18
        padding: 17
        autobind: 10
        skip: false
        asym: both
        colrow: pinky_bottom
        name: matrix_pinky_bottom
        column_net: P5
        row_net: P10
        zone: &ref_1
            columns:
                pinky: &ref_0
                    key:
                        column_net: P5
                    rows: {}
                    name: pinky
                ring: &ref_2
                    key:
                        stagger: stagger1
                        column_net: P3
                    rows: {}
                    name: ring
                middle: &ref_3
                    key:
                        stagger: stagger2
                        column_net: P2
                    rows: {}
                    name: middle
                index: &ref_4
                    key:
                        stagger: stagger3
                        column_net: P1
                    rows: {}
                    name: index
                inner: &ref_5
                    key:
                        stagger: stagger4
                        column_net: P0
                    rows: {}
                    name: inner
            rows:
                bottom:
                    row_net: P10
                home:
                    row_net: P9
                top:
                    row_net: P8
            name: matrix
        col: *ref_0
        row: bottom
        bind:
            - 10
            - 0
            - 0
            - 0
matrix_pinky_home:
    x: 0
    'y': 17
    r: 0
    meta:
        stagger: 0
        spread: 18
        splay: 0
        origin:
            - 0
            - 0
        orient: 0
        shift:
            - 0
            - 0
        rotate: 0
        adjust: {}
        width: 18
        height: 18
        padding: 17
        autobind: 10
        skip: false
        asym: both
        colrow: pinky_home
        name: matrix_pinky_home
        column_net: P5
        row_net: P9
        zone: *ref_1
        col: *ref_0
        row: home
        bind:
            - 10
            - 10
            - 10
            - 0
matrix_pinky_top:
    x: 0
    'y': 34
    r: 0
    meta:
        stagger: 0
        spread: 18
        splay: 0
        origin:
            - 0
            - 0
        orient: 0
        shift:
            - 0
            - 0
        rotate: 0
        adjust: {}
        width: 18
        height: 18
        padding: 17
        autobind: 10
        skip: false
        asym: both
        colrow: pinky_top
        name: matrix_pinky_top
        column_net: P5
        row_net: P8
        zone: *ref_1
        col: *ref_0
        row: top
        bind:
            - 0
            - 10
            - 10
            - 0
matrix_ring_bottom:
    x: 18
    'y': 12
    r: 0
    meta:
        stagger: 12
        spread: 18
        splay: 0
        origin:
            - 0
            - 0
        orient: 0
        shift:
            - 0
            - 0
        rotate: 0
        adjust: {}
        width: 18
        height: 18
        padding: 17
        autobind: 10
        skip: false
        asym: both
        colrow: ring_bottom
        name: matrix_ring_bottom
        column_net: P3
        row_net: P10
        zone: *ref_1
        col: *ref_2
        row: bottom
        bind:
            - 10
            - 0
            - 0
            - 10
matrix_ring_home:
    x: 18
    'y': 29
    r: 0
    meta:
        stagger: 12
        spread: 18
        splay: 0
        origin:
            - 0
            - 0
        orient: 0
        shift:
            - 0
            - 0
        rotate: 0
        adjust: {}
        width: 18
        height: 18
        padding: 17
        autobind: 10
        skip: false
        asym: both
        colrow: ring_home
        name: matrix_ring_home
        column_net: P3
        row_net: P9
        zone: *ref_1
        col: *ref_2
        row: home
        bind:
            - 10
            - 10
            - 10
            - 10
matrix_ring_top:
    x: 18
    'y': 46
    r: 0
    meta:
        stagger: 12
        spread: 18
        splay: 0
        origin:
            - 0
            - 0
        orient: 0
        shift:
            - 0
            - 0
        rotate: 0
        adjust: {}
        width: 18
        height: 18
        padding: 17
        autobind: 10
        skip: false
        asym: both
        colrow: ring_top
        name: matrix_ring_top
        column_net: P3
        row_net: P8
        zone: *ref_1
        col: *ref_2
        row: top
        bind:
            - 0
            - 10
            - 10
            - 0
matrix_middle_bottom:
    x: 36
    'y': 18
    r: 0
    meta:
        stagger: 6
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

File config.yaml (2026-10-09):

units:
  # Size of each key. cx and cy for choc, u and U for MX.
  kx: 16 
  ky: 16
  # key spread and padding
  # Chocofi spacing: 18 mm columns, 17 mm rows (Kailh Choc spacing)
  px: 18
  py: 17
  # From that, get the spacing between keys
  ksx: px-kx
  ksy: py-ky
  lpx: px + 1
  
  # Column stagger, in mm, copied from the Chocofi PCB (pashutk/chocofi),
  # which keeps the Fifi stagger in mm with the pinky moved down.
  stagger1: 12      # ring, above pinky
  stagger2: 6       # middle, above ring
  stagger3: -6.625  # index, below middle
  stagger4: -2.375  # inner, below index

  # CR2032 holder position, relative to the pinky bottom key
  coin_x: 22
  coin_y: -10

  # M2 case mounting holes, relative to the pinky bottom key
  hole_top_x: 24.5
  hole_top_y: 59.5
  hole_bottom_x: 2
  hole_bottom_y: -10.8
  hole_thumb_x: 76.5
  hole_thumb_y: -2.5

  # Board outline (see outlines.board_noround): end of the flat top edge,
  # bottom point under the coin cell, bottom-left corner and corner radius
  top_flat_x: 40
  bottom_x: 21
  bottom_y: -26.5
  bottom_left_y: -10
  corner_r: 3

  # Board top edge above the pinky top key (clears the XIAO's top pin row)
  mcu_top: 28.9

  xiao_length: 21
  xiao_width: 17.78

points:
  key:
    spread: 1px
    padding: 1py
  zones:
    matrix:
      columns:
        pinky:
          key:
            column_net: P5
        ring:
          key:
            stagger: stagger1
            column_net: P3
        middle:
          key:
            stagger: stagger2
            column_net: P2
        index:
          key:
            stagger: stagger3
            column_net: P1
        inner:
          key:
            stagger: stagger4
            column_net: P0
      rows:
        bottom:
          row_net: P10
        home:
          row_net: P9
        top:
          row_net: P8
    # Chocofi thumb cluster: key centres and rotations taken from the Chocofi
    # PCB, relative to the bottom pinky key. Fan is 0, -15, -30 degrees.
    thumbfan:
      anchor:
        ref: matrix_pinky_bottom
      key:
        spread: 0
      columns:
        inner:
          key:
            adjust:
              shift: [48.1, -8.59]
            column_net: P2
        middle:
          key:
            adjust:
              shift: [68.15, -11.18]
              rotate: -15
            column_net: P1
        home:
          key:
            adjust:
              shift: [88.75, -14.39]
              rotate: -30
            column_net: P0
      rows:
        thumb:
          row_net: P4

outlines:
  # One straight-edged polygon with rounded corners. It hugs the key grid,
  # the XIAO/power switch strip on top, the CR2032 below the pinky/ring
  # columns and the thumb fan, with a single notch between the inner column
  # and the outermost thumb key.
  board_noround:
    main:
      what: polygon
      points:
        - ref: matrix_pinky_top # Top left, above the XIAO
          shift: [-0.5lpx, mcu_top]
        - ref: matrix_pinky_top # End of the flat top edge
          shift: [top_flat_x, mcu_top]
        - ref: matrix_inner_top # Top right, diagonal down from the flat top
          shift: [0.5lpx, 0.5py+1]
        - ref: matrix_inner_bottom # Bottom of the inner column (notch corner)
          shift: [0.5lpx, -0.5py]
        - ref: thumbfan_home_thumb # Outer thumb, top right
          shift: [0.5lpx+0.5, 0.5py+0.5]
        - ref: thumbfan_home_thumb # Outer thumb, bottom right
          shift: [0.5lpx+0.5, -0.5py-0.5]
        - ref: matrix_pinky_bottom # Under the coin cell, tangent to it
          shift: [bottom_x, bottom_y]
        - ref: matrix_pinky_bottom # Bottom left, below the pinky column
          shift: [-0.5lpx, bottom_left_y]
  board:
    - what: outline
      name: board_noround
      fillet: corner_r
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

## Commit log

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2025-09-09 fix(layout): add splay and library for footprint
    [config.yaml]
2025-09-09 chore(pcb): add extra parts
    [board.dxf, board_noround.dxf, main.kicad_pcb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]
2025-09-10 Revert "chore(pcb): add extra parts"
    This reverts commit bf00a23c4da58c788347c8aacf8456471ae03a72.
    [board.dxf, board_noround.dxf, main.kicad_pcb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]
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2025-09-10 feat(pcb): add pcb files generated by ergogen
    [board.dxf, board_noround.dxf, demo.dxf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]
2025-09-10 fix(routing): route pcb
    [main.kicad_pcb]
2025-09-10 feat(3dmodel): add 3d model of swtich
    [main.kicad_pcb]
2025-09-10 fix(battery): connect battery connector with slider switch
    [config.yaml]
2025-09-10 feat(gerber): add gerber files
    [main.kicad_pcb]
2025-09-11 chore(silkscreen): add markings
    [main.kicad_pcb]
2025-09-11 fix(splay): rotate middle thumb key by 5 degree and move 1 mm out
    [config.yaml]
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2026-10-08 Close the design gaps: coin cell, per-key LEDs, ZMK dongle, JLC files, case
    - Reversible footprints (2-pin SMD, SOT-23, slide switch, CR2032 holder,
    M2 holes) that mirror their B-side copper, so one PCB assembles as the
    left half on top and the right half on the bottom.
    - Coin cell power path (CR2032 -> switch -> B5819W -> XIAO BAT+), per-key
    0603 LEDs with one PWM-dimmed low-side MOSFET.
    - Routed board via Freerouting plus a finisher for nets it misreads, GND
    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
    [board.dxf, board_noround.dxf, bom.csv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]
2026-10-08 Match the Chocofi key spacing, stagger and thumb cluster
    Key centres now come straight from the Chocofi PCB (pashutk/chocofi):
    18 x 17 mm pitch, column stagger 12 / 6 / -6.625 / -2.375 mm, thumbs at
    fixed offsets from the bottom pinky key with a 0 / -15 / -30 degree fan.
    The board top edge and power switch are now set from the pinky key so the
    XIAO's top pin row stays on the board, and the thumb M2 hole moved off the
    middle thumb diode. finish_routes.py reroutes tracks Freerouting leaves
    inside the 0.3 mm edge rule, and the pour ties the XIAO's via-like GND
    pads in solidly. Board rerouted, DRC has no new errors, gerbers, CPL and
    case regenerated.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
    [board.dxf, board_noround.dxf, demo.dxf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]
2026-10-09 Add two case versions: Aronia-style folding case and joinable split trays
    make_case.py now only exports the board geometry (outline, holes, key
    centres, XIAO, switch and CR2032 positions) to case/board.scad. Two
    hand-written OpenSCAD designs build on it:
    - fold.scad: thin frame + screwed bottom cover per half after the Aronia
    case, joined by a double hinge on 2 mm brass rods with printed links.
    Opens flat as a uniboard and folds keys-to-keys with a gap sized for the
    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
    [board.scad, common.scad, fold.scad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]
2026-10-09 Join the split trays with a screwed bridge plate instead of dog-bone keys
    The two small slide-in keys let the trays hinge at the seam, so the joined
    board could fold or rock when one half was not fully supported. A plate
    recessed flush into the top across the seam, screwed into both trays with
    three M2 x 4 mm screws each, holds them rigid. The plate replaces the centre
    dongle tray; unscrew it to split the board.
    Claude-Session: https://claude.ai/code/session_01Wd79AKpL9gbYjwudbTjCxH
    [fold_left_cover.stl, fold_left_frame.stl, fold_right_cover.stl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]
2026-10-09 Join the split trays with slide-in dovetail plates, no screws
    Two tapered dovetail plates slide into a groove along the seam, one from
    the back edge and one from the front, and wedge tight flush with the top.
    Their undercut sides grip both trays, so the joined board can't pull apart,
    lift, or hinge at the seam, without screws or tools.
    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
    [fold_left_cover.stl, fold_left_frame.stl, fold_right_cover.stl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]
2026-10-09 Join the split trays with one slide-on I-beam clip
    The clip has a wide base under both trays (about half of each underside),
    a web through the seam and a 45-degree bridge in a groove along the top, so
    the joined board is supported from below and held from above. It slides on
    from the back, stops against a back lip and clicks into two dimples; no
    screws or tools. Replaces the two top-only dovetail plates.
    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
    [fold_left_cover.stl, fold_left_frame.stl, fold_right_cover.stl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]
2026-10-09 Draw the board outline as one straight-edged polygon
    The outline was the union of the key rectangles, the XIAO strip, the
    coin-cell circle and a bottom polygon: a stepped top edge, a round bulge
    under the CR2032 and small notches, with 1 mm fillets. It is now a single
    8-sided polygon with 3 mm rounded corners: flat top over the XIAO and power
    switch, a diagonal down to the inner column, a straight right edge, one
    notch for the outer thumb key and a straight bottom tangent under the coin
    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
    [board.dxf, board_noround.dxf, main.kicad_pcb]
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2026-10-09 Re-route the board for the new outline
    Full scripts/build_pcb.sh run: Freerouting, finish_routes, GND pours, DRC
    (0 unconnected pads, nothing new versus master) and regenerated Gerbers.
    BOM and CPL are unchanged.
    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
    [ultra-choc-wings.kicad_pcb]
2026-10-09 Rebuild the case STLs around the new board outline
    Both cases are generated from case/board.scad, so the fold frames, covers
    and split trays and clip follow the new straight edges.
    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
    [board.scad, fold_left_cover.stl, fold_left_frame.stl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]
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2026-10-09 fix(update): update the kicad version
    [ultra-choc-wings.kicad_pcb]
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2026-10-09 Add the ucw footprint library: one footprint per part type
    Exported from the routed board: PG1316S switch, SOD-123 diode, 0603 LED,
    0603 and 0805 passives, SOT-23 MOSFET, CR2032 holder, SPDT slide switch,
    RAW pad, M2 hole and the flippable XIAO. All are the reversible versions.
    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
2026-10-09 Add the schematic of one half
    All 84 parts with their nets as net labels: the 18 key blocks (switch,
    diode, LED, LED resistor), the XIAO, the CR2032 power path, the LED driver
    and the mounting holes. Its netlist matches the board pad for pad.
    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
    [ultra-choc-wings.kicad_sch]
2026-10-09 Link the board footprints to the ucw library and the schematic
    Each footprint now names its ucw library footprint and carries the path of
    its schematic symbol, so cross-probing and Update PCB from Schematic match
    part for part. Text-only edit of the KiCad 10 board; nothing moved.
    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
    [ultra-choc-wings.kicad_pcb]
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2026-10-09 Regenerate the schematic with wires and global labels
    Net names now equal the board's exactly (checked against the netlist, no
    differences). The key matrix is laid out as row label - diode - switch -
    column label and LED_K - LED - resistor - VCC3.
    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
    [ultra-choc-wings.kicad_sch]
2026-10-09 Relink the board footprints to the schematic
    Moves each footprint's path next to (attr) and adds sheetname and sheetfile,
    as KiCad 10 writes them. Text-only edit, nothing moved.
    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
    [ultra-choc-wings.kicad_pcb]
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2026-10-09 Link the 3D models into the board footprints
    80 footprints on the switch side get a (model) line; the mounting holes and
    the RAW pad have none. Text-only edit, nothing moved.
    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
    [ultra-choc-wings.kicad_pcb]
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2026-10-09 Re-route the board with the parts under the switches
    [main.kicad_pcb, ultra-choc-wings.kicad_pcb]
2026-10-09 Regenerate gerbers and JLCPCB placement files
    [cpl-left-top.csv, cpl-right-bottom.csv]
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2026-10-09 Regenerate case STLs
    [fold_left_cover.stl, fold_left_frame.stl, fold_right_cover.stl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]
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2026-10-09 Re-route the board with the diode next to the LED
    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
    [main.kicad_pcb, ultra-choc-wings.kicad_pcb]
2026-10-09 Regenerate gerbers, BOM and placement files for the SOD-323 diode
    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
    [bom.csv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]
2026-10-09 Refresh schematic links, libraries and 3D previews
    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
    [ultra-choc-wings.kicad_sch]
2026-10-09 Regenerate case STLs
    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
    [fold_left_cover.stl, fold_left_frame.stl, fold_right_cover.stl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]
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
